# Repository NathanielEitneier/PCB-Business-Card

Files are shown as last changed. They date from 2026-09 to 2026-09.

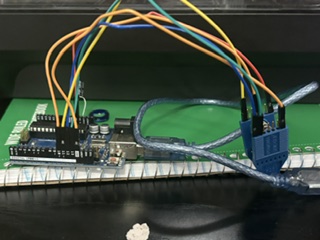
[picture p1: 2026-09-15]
PCB-BusinessCard/images/ChipFlash.jpeg

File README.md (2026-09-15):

# PCB Business Card — NFC + Onboard Game

A working business card designed, programmed, debugged, and soldered by myself.

Untitled design

## What this is

My first PCB design: a business-card-sized board built around an ATtiny84, with an onboard NFC tag and a small interactive game built into the card itself. Tap it with a phone and it links straight to this GitHub. I wanted this to be a real learning project, so I designed and programmed everything independently.

## Features

- **NFC tap-to-link** — taps open my GitHub / personal site directly from the card
- **Onboard game** — playable using the card's built-in switches and LEDs
- **ATtiny84-driven** — no separate dev board, just the chip on the card itself
- **Custom PCB** — designed, ordered, and hand-assembled from scratch (5 boards ordered)

## How it works

| Component | Pins |
|---|---|
| LEDs | Arduino-equivalent pins 5, 6, 7 |
| Switches | Arduino-equivalent pins 2, 3, 4 |
| MCU | ATtiny84 |

The game logic runs entirely on the ATtiny84, reading input from the three switches and driving the three LEDs as output/feedback. It is a memorization game where the LEDs will blink in a sequence and you must press the corresponding buttons that match that sequence to continue. For each sequence you get right another step is added. The game is won when 15 steps is reached.

## Build notes

- Programmed the ATtiny84 **before** soldering it onto the card, to avoid the risk of a bad reflow bricking a chip I couldn't easily reprogram in place
- The PCB was designed in KiCad
- nt3h1101 nfc chip
- Ordered 5 boards for assembly and handout

## What I learned

This was my first time taking a board from schematic to a physically assembled, working product. From this I gained a deeper understanding of the design process and how each step builds upon the last. This made me realize the importance of good habits like proper labeling and footprints on schematics when designing a PCB, because any short cuts taken will come back to haunt you later on in the design. I learned a few lessons the hard way. Programming the board with a USBasp did not work for me after hours of trying, and I eventually found a way to do it with a Arduino Uno R3. Additionally, soldering the SMD MCUs was a nightmare and if I make this project again I will switch to a through-hole MCU. Overall, the most important thing I learned from this was that I am capable of teaching myself and attempting projects that I may not have the skills to complete when I start them.
## Hardware files

- [View Schematic](PCB-BusinessCard/hardware/PCB_BusinessCard.kicad_sch)
- [Bill of Materials](PCB-BusinessCard/hardware/bom.csv)
- [Link to Demo Video](PCB-BusinessCard/images/DemoVid1.mov)
- [Link to Demo Video2 ](PCB-BusinessCard/images/DemoVid2.mov)

## Contact

**Nathaniel Eitneier**
Electrical Engineering, University of Florida
📧 eitneiern@ufl.edu
🔗 [github.com/NathanielEitneier](https://github.com/NathanielEitneier)

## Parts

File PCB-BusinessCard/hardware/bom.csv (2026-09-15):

Designator | Footprint | Quantity | Value | LCSC Part #
BT1 | BatteryHolder_Keystone_1057_1x2032 | 1 | C969911
C1 | 0805 | 1 | .1u
C2, C3 | 0805 | 2 | 10pF
ORANGE1 | 0805 | 1 | KT-0805O
R1 | 0805 | 1 | 62
R2, R3 | 0805 | 2 | 120
RED1 | 0805 | 1 | KT-0805R
SW1, SW2, SW3 | SW_SPST_EVQP2_ShortPushTravel_H2.1mm | 3 | EVQP2R02M
U1 | SOIC-14_3.9x8.7mm_P1.27mm | 1 | ATtiny84-20SS
U2 | IC_NT3H1101W0FHK | 1 | NT3H1101W0FHKH
YELLOW1 | 0805 | 1 | KT-0805Y

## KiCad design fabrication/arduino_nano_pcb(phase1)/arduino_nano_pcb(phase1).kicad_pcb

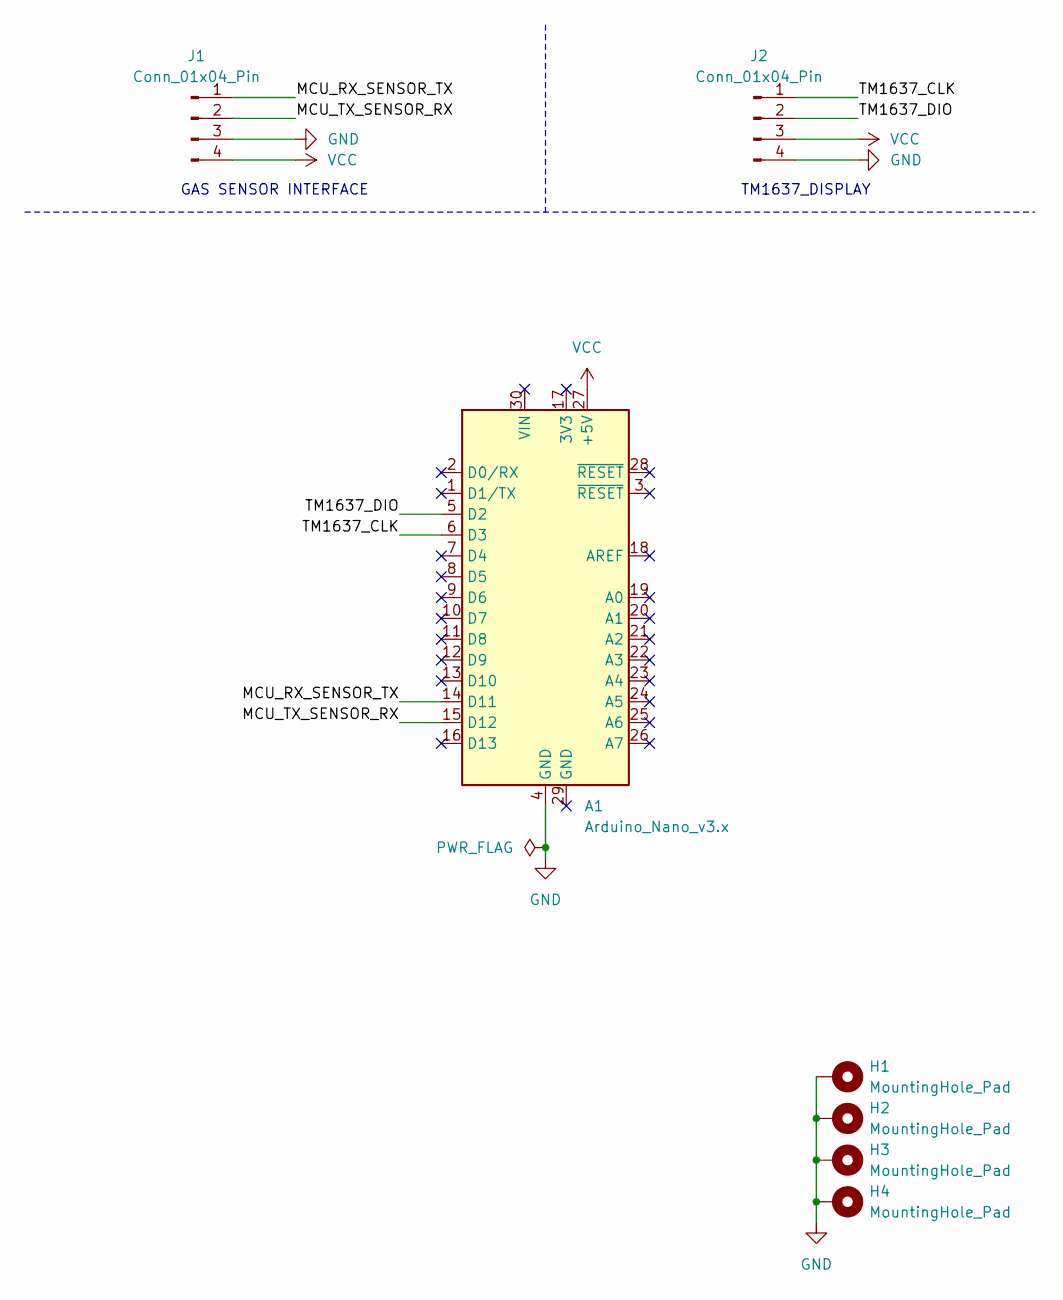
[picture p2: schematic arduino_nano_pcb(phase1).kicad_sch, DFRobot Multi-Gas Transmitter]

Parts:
A1: Arduino_Nano_v3.x; Arduino_Nano
H1, H2, H3, H4: MountingHole_Pad; MountingHole_5mm_Pad_TopBottom
J1: Conn_01x04_Pin; PinHeader_1x04_P2.54mm_Horizontal
J2: Conn_01x04_Pin; TM1637

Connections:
/MCU_RX_SENSOR_TX: A1.14 (D11), J1.1
/MCU_TX_SENSOR_RX: A1.15 (D12), J1.2
/TM1637_CLK: A1.6 (D3), J2.1
/TM1637_DIO: A1.5 (D2), J2.2
GND: A1.4 (GND), H1.1 (1_1), H2.1 (1_1), H3.1 (1_1), H4.1 (1_1), J1.3, J2.4
VCC: A1.27 (+5V), J1.4, J2.3

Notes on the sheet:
TM1637_DISPLAY
GAS SENSOR INTERFACE

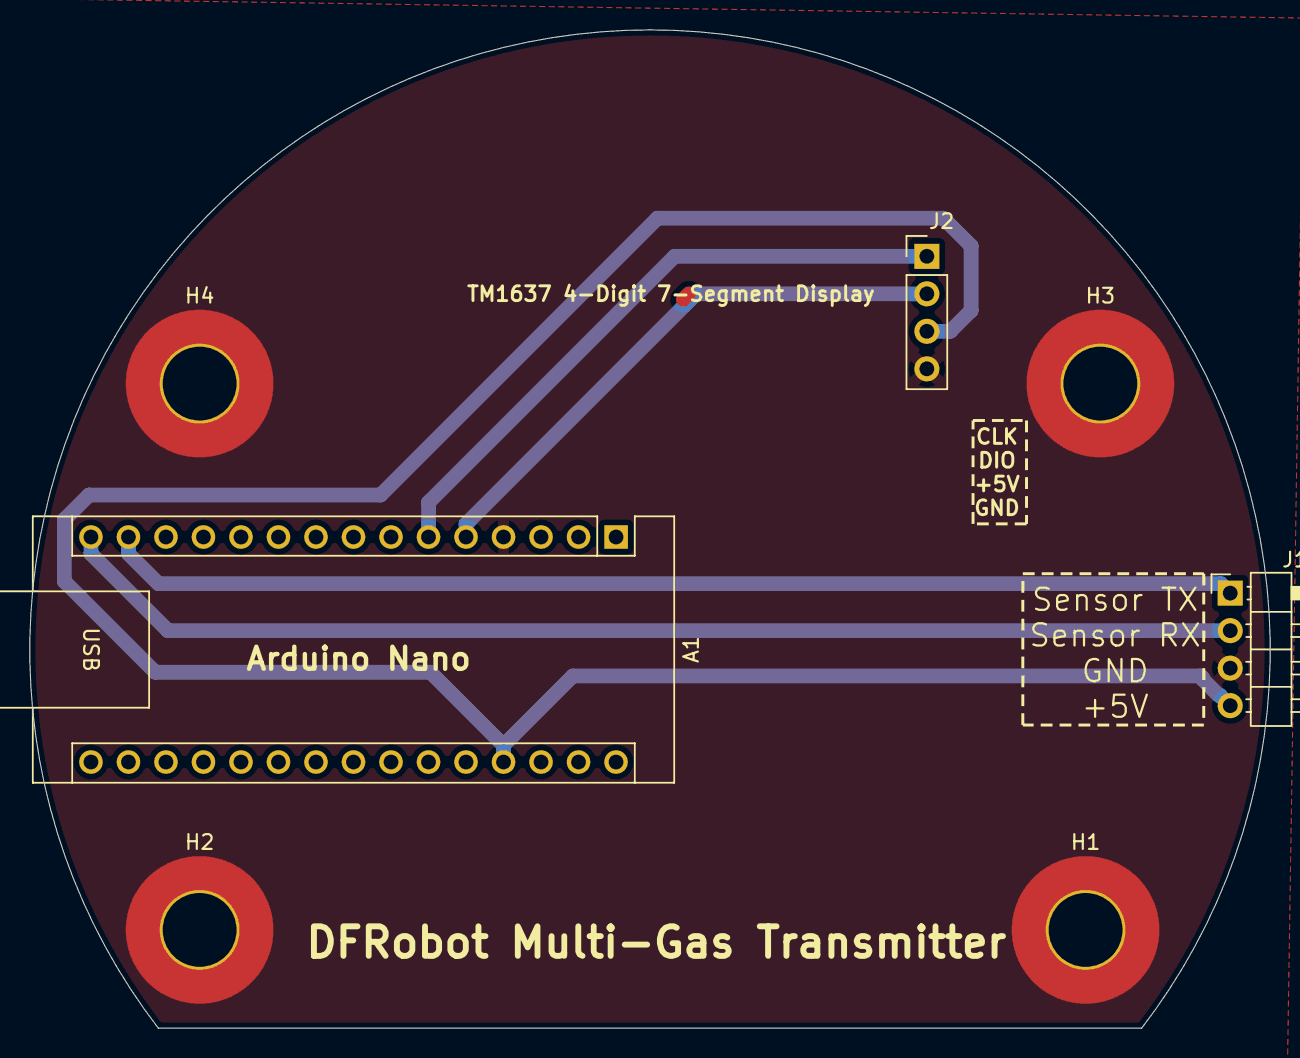
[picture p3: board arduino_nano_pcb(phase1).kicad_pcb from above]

Board: 2 copper layers, 84.0 x 67.6 mm, 7 parts (0 on the bottom side), 6 nets.

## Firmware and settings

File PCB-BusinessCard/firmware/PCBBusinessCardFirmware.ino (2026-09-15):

#include <Arduino.h>
#include <avr/sleep.h>
#include <avr/interrupt.h>

// LED pins matching ATtiny84 arduino pinout
const uint8_t LED_PINS[3] = {5, 6, 7};

// Button pins MATCH ORDER TO BUTTONS OR GAME WILL NOT WORK
const uint8_t BUTTON_PINS[3] = {2, 3, 4}; // Order matters to match LED outputs

// Game constants
const uint8_t Max_Sequence = 15;
const unsigned long LED_ON_TIME = 300;
const unsigned long LED_OFF_TIME = 150;

// Game sequence
uint8_t sequence[Max_Sequence];

// Game states
enum GameState {
  START,
  Show_Sequence,
  Player_Input,
  Game_Over,
  WIN
};

GameState gameState = START;
uint8_t sequenceLength = 1;

// Empty ISR wakes the mcu up when a pin is changed 
ISR(PCINT0_vect) {
}

void setup() {
  for (uint8_t i = 0; i < 3; i++) {
    pinMode(LED_PINS[i], OUTPUT);
  }
  for (uint8_t i = 0; i < 3; i++) {
    pinMode(BUTTON_PINS[i], INPUT_PULLUP);
  }

  randomSeed(analogRead(0));

  set_sleep_mode(SLEEP_MODE_PWR_DOWN);
  GIMSK |= (1 << PCIE0);                                    // enable pin-change interrupts on PORTA
  PCMSK0 |= (1 << PCINT2) | (1 << PCINT3) | (1 << PCINT4);  // watch pins 2, 3, 4
}
//state machine inside loop controls game 
void loop() {
  switch (gameState) {
    case START:
      sequenceLength = 1;
      addToSequence();
      gameState = Show_Sequence;
      break;

    case Show_Sequence:
      showSequence();
      gameState = Player_Input;
      break;

    case Player_Input:
      if (getPlayerInput()) {
        if (sequenceLength >= Max_Sequence) {
          gameState = WIN;
        } else {
          sequenceLength++;
          addToSequence();
          gameState = Show_Sequence;
        }
      } else {
        gameState = Game_Over;
      }
      break;

    case Game_Over:
      gameOver();
      gameState = START;
      break;

    case WIN:
      winGame();
      gameState = START;
      break;
  }
}

void flashLED(uint8_t led) {
  digitalWrite(LED_PINS[led], HIGH);
  delay(LED_ON_TIME);
  digitalWrite(LED_PINS[led], LOW);
  delay(LED_OFF_TIME);
}

int8_t waitForButton() {
  while (true) {
    bool anyPressed = false;
    for (uint8_t i = 0; i < 3; i++) {
      if (digitalRead(BUTTON_PINS[i]) == LOW) anyPressed = true;
    }

    if (!anyPressed) {
      sleep_mode();      // Waits for input to wake it
      continue;
    }
// button debouncing function
    for (uint8_t i = 0; i < 3; i++) {
      if (digitalRead(BUTTON_PINS[i]) == LOW) {
        delay(20);
        if (digitalRead(BUTTON_PINS[i]) != LOW) continue; // was noise, not a real press

        while (digitalRead(BUTTON_PINS[i]) == LOW);        // wait for release
        delay(20);                                          // debounce the release

        return i;
      }
    }
  }
}

void addToSequence() {
  sequence[sequenceLength - 1] = random(0, 3);
}

void showSequence() {
  for (uint8_t i = 0; i < sequenceLength; i++) {
    flashLED(sequence[i]);
  }
}

bool getPlayerInput() {
  for (uint8_t i = 0; i < sequenceLength; i++) {
    int8_t playerInput = waitForButton();
    if (playerInput != sequence[i]) {
      return false;
    }
  }
  return true;
}
// sequence showing game was lost
void gameOver() {
  for (uint8_t i = 0; i < 3; i++) {
    digitalWrite(LED_PINS[i], HIGH);
  }
  delay(500);
  for (uint8_t i = 0; i < 3; i++) {
    digitalWrite(LED_PINS[i], LOW);
  }
  delay(500);
}
// Victory celebration for if the game is beaten
void winGame() {
  for (uint8_t i = 0; i < 3; i++) {
    flashLED(i);
  }
  for (uint8_t i = 0; i < 3; i++) {
    digitalWrite(LED_PINS[i], HIGH);
  }
  delay(500);
  for (uint8_t i = 0; i < 3; i++) {
    digitalWrite(LED_PINS[i], LOW);
  }
}
